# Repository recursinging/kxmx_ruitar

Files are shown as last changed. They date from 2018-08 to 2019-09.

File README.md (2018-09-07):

# kxmx_ruitar

A guitar shaped MIDI/OSC instrument

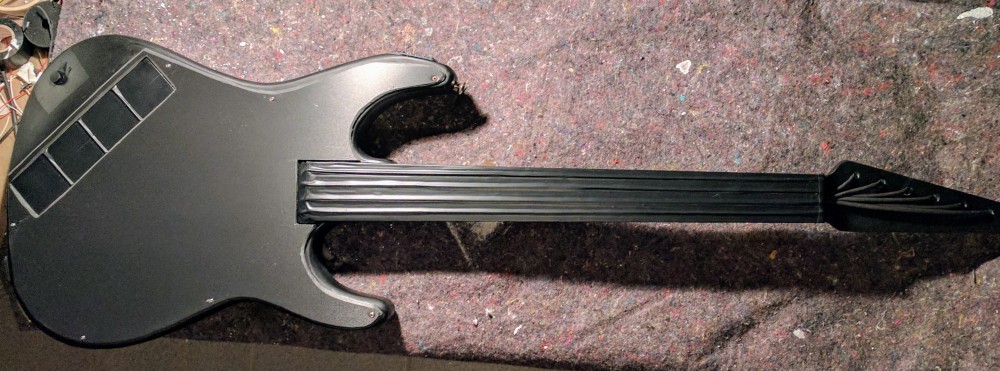
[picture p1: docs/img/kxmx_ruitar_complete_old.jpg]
kxmx_ruitar - Complete - Detail


## The Idea

The goal of this project is pretty simple; Take the general functionality of your typical MIDI keyboard or control surface and implement it (robustly, and with low latency) in the form factor of a guitar.  The motivation is a a little less straightforward. Three things:

1. I wanted to wear it on stage while maintaining the freedom to move about.  
1. I wanted to make it myself.
1. It didn't want to spend a fortune.

I like the form factor of a guitar because it can look quite traditional in a rock band context, but upon closer inspection is clearly not.  This reflects my taste in music, superficially recognizable, but substantially deviant.  While I can play the guitar, I didn't feel it necessary that a functional [guitar be augmented](http://lividinstruments.com/products/guitar-wing/) with MIDI controller capabilities, unless the two can be [seamlessly combined](https://www.rorguitars.com/products/expressiv-midi-pro). This is primarily because my single-threaded brain just cannot effectively handle playing an instrument well, while controlling other parameters. 

Because a guitar hangs down in front of you, facing out, visual controls and feedback are pretty useless.  [A touch screen on the front of the guitar](https://misa-digital.myshopify.com/products/tri-bass) for example, is effectively a touch-pad for the player and a light show for the audience. Therefore I am mostly interested in tactile type sensors which can be blindly interacted with.

The DIY approach is simply an excuse to get lost in the details of interesting technical challenges instead of practicing, or composing actual music. 

Regarding limiting cost... Yeah, anyone who has ever attempted a DIY project like this knows it's actually BS. There is no competing with the economies of scale that a market product has. We DIYers like to trick ourselves by spreading the costs into tiny chunks, over many months. But, I consider the premium an investment in enjoyment and the knowledge gained along the way. So that's how it ended up here.  

## The (current) BOM

* 1 [Teensy 3.6](https://www.pjrc.com/store/teensy36.html) with SD card
* 1 Junk electric guitar, or similarly shaped object.
* 4 500mm [ThinPot](http://www.spectrasymbol.com/product/thinpot/) Membrane Potentiometers (Strings)
* 4 38x38mm [FSR](https://www.interlinkelectronics.com/fsr-406) Pressure Sensors (Pads)
* 1 [Joystick](https://www.adafruit.com/product/444)
* 4 45mm [Slider Potentiometers](https://www.digikey.com/product-detail/en/tt-electronics-bi/PS45-21PC3BR10K/987-1409-ND/2620678) (Faders)
* 4 [LED Buttons](https://www.sparkfun.com/products/10442) (Toggles)
* 1 [SSD1306 64x32 OLED display](https://www.adafruit.com/product/326)
* A diverse set of 0805 SMD resistors and capacitors
* Bits and Bobs (proto board, hookup wire, solder, tape, velcro, etc.)

(With Optional Headstock)

* 1 [Teensy LC](https://www.pjrc.com/teensy/teensyLC.html)
* 4 [RGB LED Rotary Encoders](https://www.sparkfun.com/products/10982)
* 1 [ADXL345 3 Axis Accelerometer](https://www.sparkfun.com/datasheets/Sensors/Accelerometer/ADXL345.pdf) (Accel)
* 1 [TLC5940 PWM Controller](http://www.ti.com/lit/ds/symlink/tlc5940.pdf)
* A diverse set of 0805 SMD resistors and capacitors
* [The ruitar-head PCB]()

## The Build

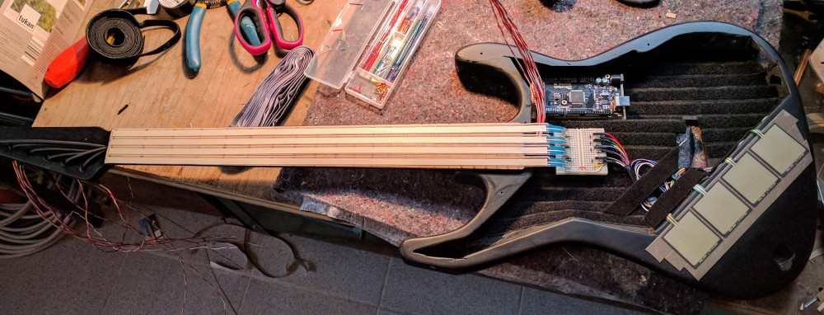
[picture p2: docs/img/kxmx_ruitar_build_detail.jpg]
kxmx_ruitar - Body - Detail


The guitar used was a junk no-name electric.  I hollowed out from the front of the body with an oscillating multi-tool and a wood blade, leaving space for the FSRs.  Because the body is plywood, it was pretty easy to remove the bulk of the material.  I spray-painted everything black and carpeted the inside with adhesive Velcro strips (loop side). This has been quite helpful for cable management and general experimentation.  Just put some hook Velcro to the bottom of a breadboard and stick it in there. Need a USB Hub? Raspberry Pi? Velcro!

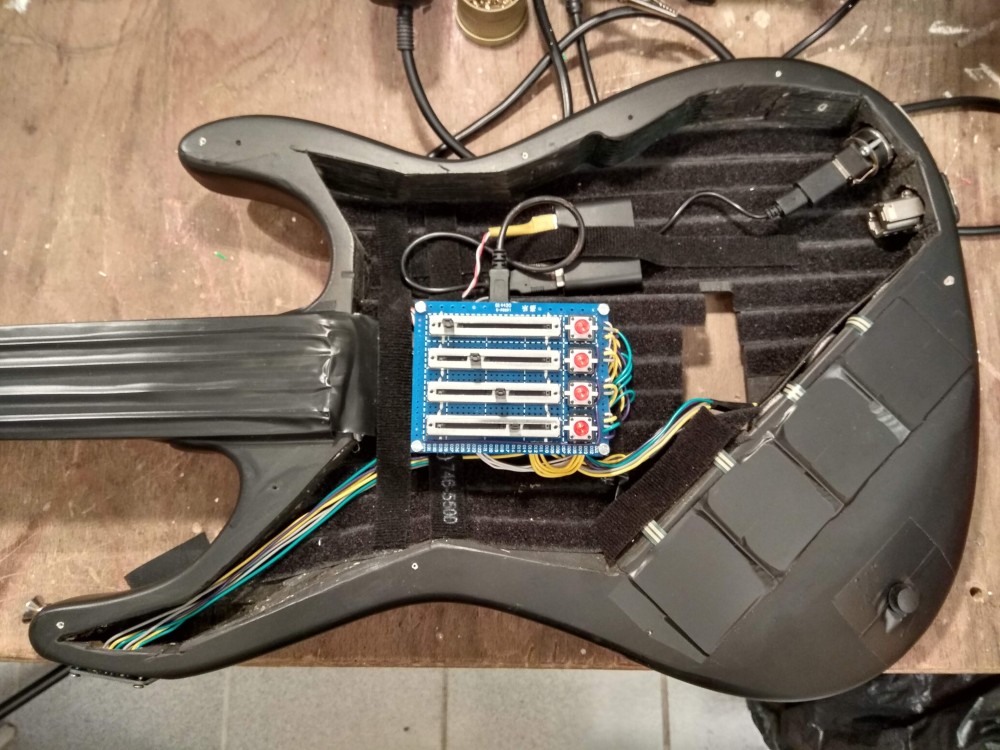
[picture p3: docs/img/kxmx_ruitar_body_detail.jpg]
kxmx_ruitar - Body - Detail


The FSRs are attached with some double sided foam tape which holds them solidly in place and gives them a little bit of padding, which is good when you are banging on them with your knuckles.  The little thumb joystick is mounted in the body with hot glue, and wired through a hole bored into the body cavity. The joystick is meant to be moved with the palm of your hand, allowing you to modulate parameters while tapping on the FSRs... In practice, little thumb joysticks like that are junk, they have too little travel to introduce any decent dynamic.  I am actively looking for an alternative, larger joystick with more travel.

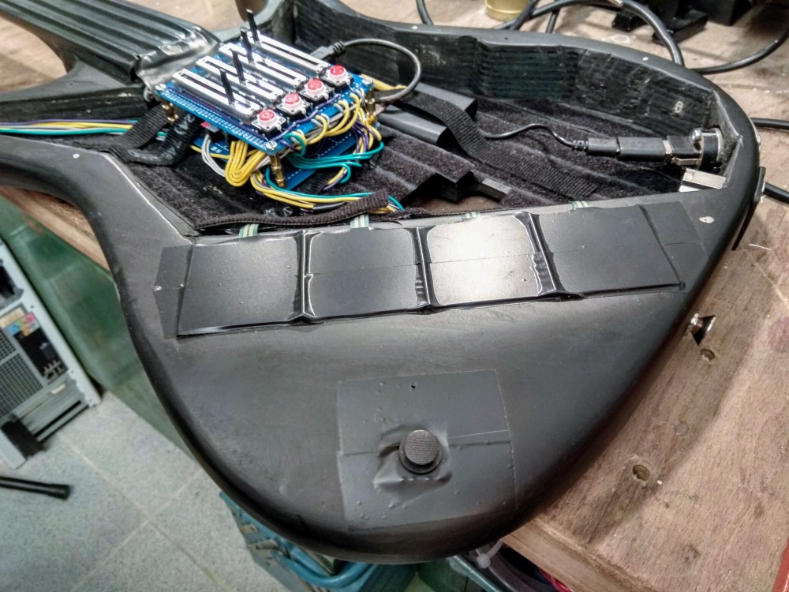
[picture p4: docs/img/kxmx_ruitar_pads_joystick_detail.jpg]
kxmx_ruitar - Body - Detail Pads and Joystick


The first prototype was done using breadboards and an Arduino Mega2650 clone.  When it was finally functional, I found the latency to be unacceptable, the breadboard connections were fragile and problematic,and I also found it lacking interface components.  So, I swapped the Mega2650 for a Teensy 3.6, soldered all the connections using some protoboard, and added the four faders plus four LED buttons. The result is this new prototype module. I'm designing a PCB which will replace this.

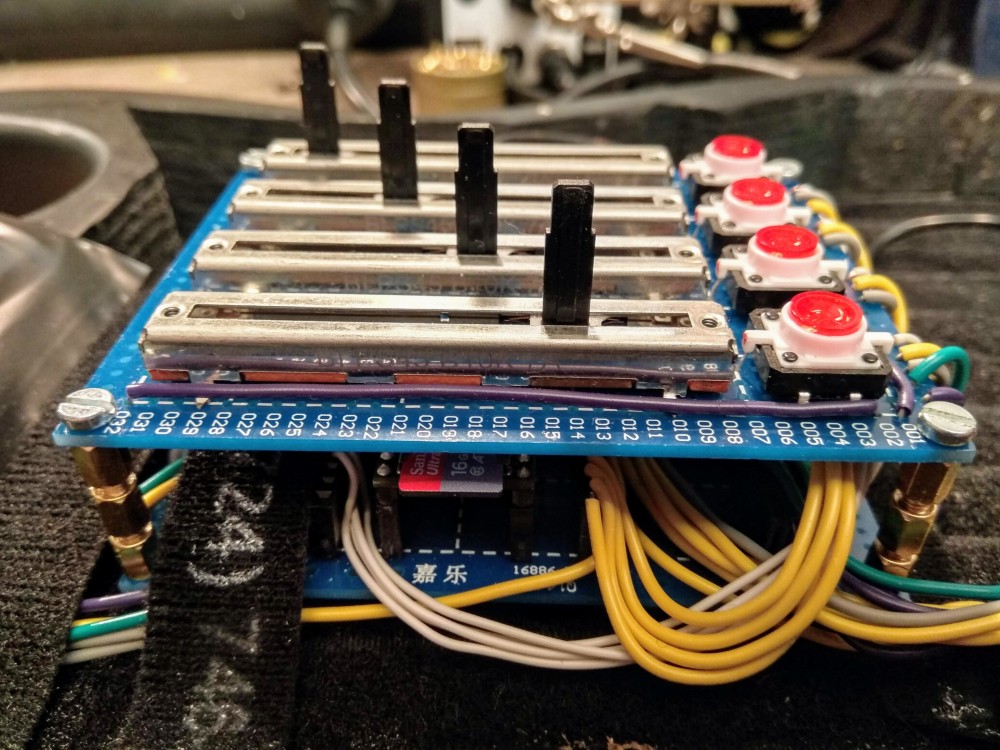
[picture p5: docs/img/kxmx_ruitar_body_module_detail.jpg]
kxmx_ruitar - Body - Detail Faders and Toggles


There are USB-A and RJ-45 jacks to the side using some nice, locking Neutrik jacks.  Because the Teensy's advanced USB capabilities, there is only USB IO at the moment.  The unused RJ-45 is for some future ideas.

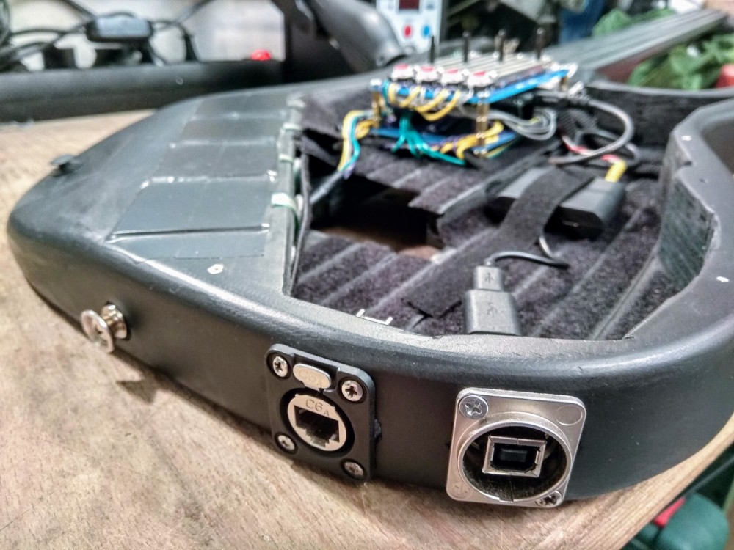
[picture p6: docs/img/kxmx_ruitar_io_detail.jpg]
kxmx_ruitar - IO - Detail


There is an SSD1306 64x32 OLED display mounted to the side of the body of the guitar. I simply flattened a little part of the edge with a belt sander, and drilled a hole into the body cavity for the wires. A 3d-printed protective case surrounding the display would be useful.

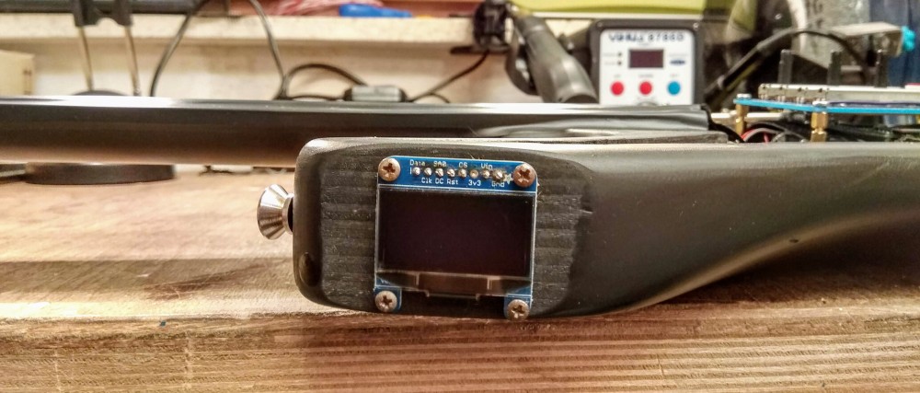
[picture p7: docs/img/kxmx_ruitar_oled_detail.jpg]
kxmx_ruitar - Body - Detail OLED


There is a cover for the body cavity I cut out of plastic to hide the unruly guts (although the aesthetics of the exposed internals are also appealing).  Note that this photo was also taken before the faders and buttons were added, which means that the cover, in that form is not currently usable, but I'm still unsure about the final positions of those components anyhow. 

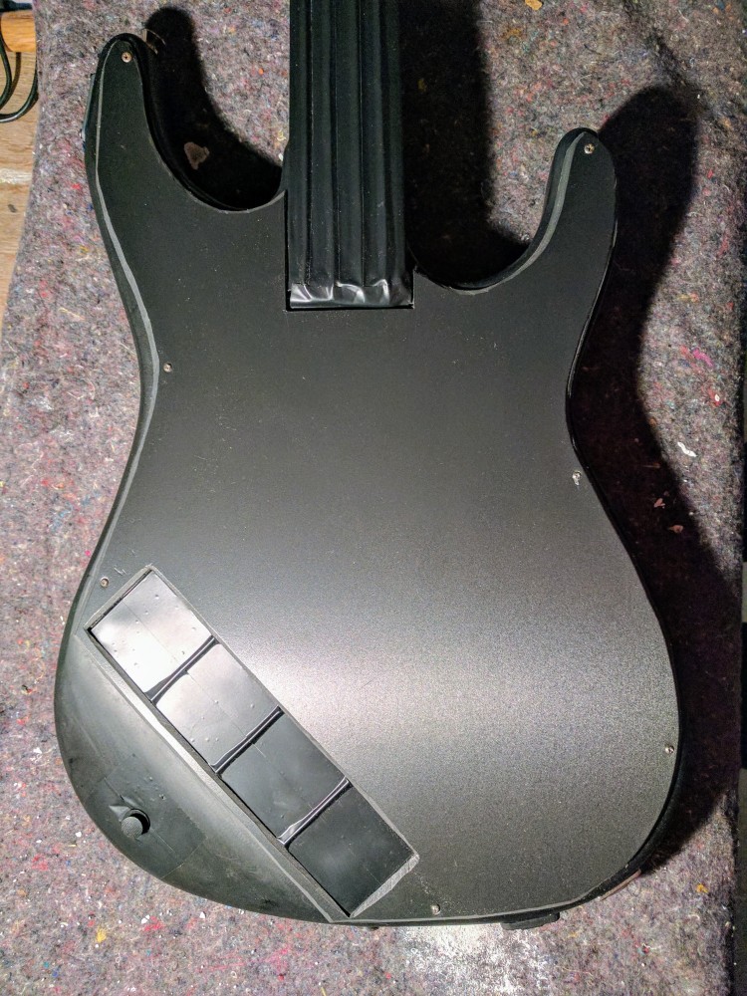
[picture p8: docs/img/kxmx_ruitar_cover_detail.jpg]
kxmx_ruitar - Cover - Detail


The neck was a huge pain. Removing the truss rod required brute force, but afterward I had a cable channel through which I am able to pull wires from the body, up to the head stock. In order to adhere the membrane potentiometers, I needed to flatten the fingerboard. I didn't have any good ideas how, so I ended up just sanding the frets down with a belt sander. There are no photos of this process because I was too busy cursing. The result is OK but if you want to try this yourself, I'd recommend looking for a cheap neck without a fingerboard (although I was unable to find one). Once flattened I attached the membrane potentiometers and covered them with a layer of electrical tape.  I then laid some straightened 14 gauge solid core wire down the middle of each sensor, and put another layer of tape on top.  This provides some tactile feedback as to where the sensors actually are, and really helps the play-ability.  The position tracking through the wire is excellent.

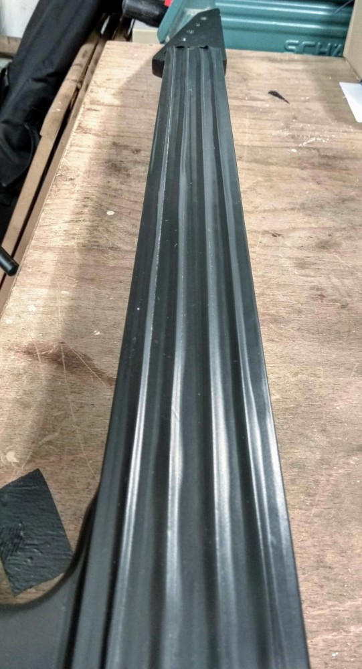
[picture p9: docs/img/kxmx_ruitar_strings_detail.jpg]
kxmx_ruitar - Body - Detail Strings


[The headstock](https://github.com/recursinging/kxmx_ruitar/tree/master/ruitar-head) is a separate entity with its own microcontroller, a ([Teensy LC](https://www.pjrc.com/teensy/teensyLC.html)) acting as an I²C slave device.  It is attached to the headstock of a guitar. I've connected it to the body module with wires pulled through the neck of the guitar.  I removed all the tuning hardware and screwed it directly to the headstock.  Currently, it is quite exposed and fragile.  I'd like to design a 3d printed protective cover for it.

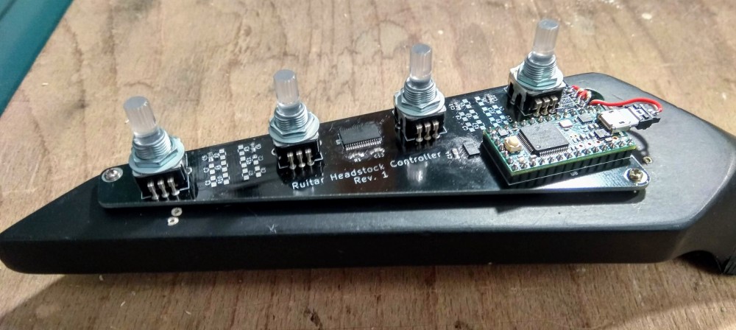
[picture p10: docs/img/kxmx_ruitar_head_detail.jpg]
kxmx_ruitar - Head - Detail


Put all together and you have a ruitar!

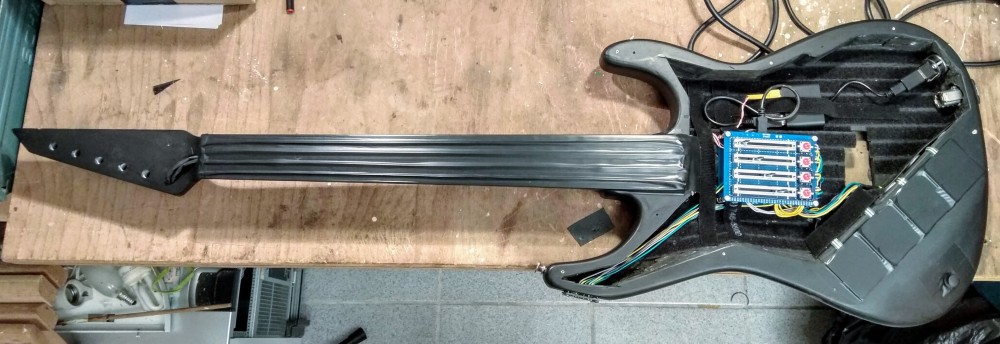
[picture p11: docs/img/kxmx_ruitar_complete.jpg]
kxmx_ruitar - Complete - Current - Detail


## Schematics

TODO

## Firmware

Because the headstock and body have their own microcontrollers, this project is split into two sections, the *ruitar-body* and the *ruitar-head*.  The directory layouts of both projects are currently set up for [platformio](https://platformio.org/), it works. It's not bad.

### [ruitar-body](https://github.com/recursinging/kxmx_ruitar/tree/master/ruitar-head)

The ruitar-body is the core of the instrument, effectively a variety of sensors attached to a microcontroller (a [Teensy 3.6](https://www.pjrc.com/store/teensy36.html)).  These sensors are sampled via the microcontroller ADCs, the values are calculated and, if appropriate, MIDI and OSC messages are sent out. (currently via USB to a PC).

The logic controlling when and what messages to send is configurable by a INI style text files on an SD card. These files can be considered "Presets" and can be copied, modified, renamed, and saved to the SD card.  

TODO - Include config file example

I had plans to make presets configurable through the sensors, and OLED display, but I found the OSC GUI much easier and more powerful, so the OLED display is currently relegated to display some basic debugging info at the moment.  Perhaps there is a better use for it, or the SPI pins it is occupying?

Presets can also be edited via OSC using [the GUI definition](https://github.com/recursinging/kxmx_ruitar/blob/master/osc-gui.json) for [Open Stage Control](https://osc.ammd.net/)

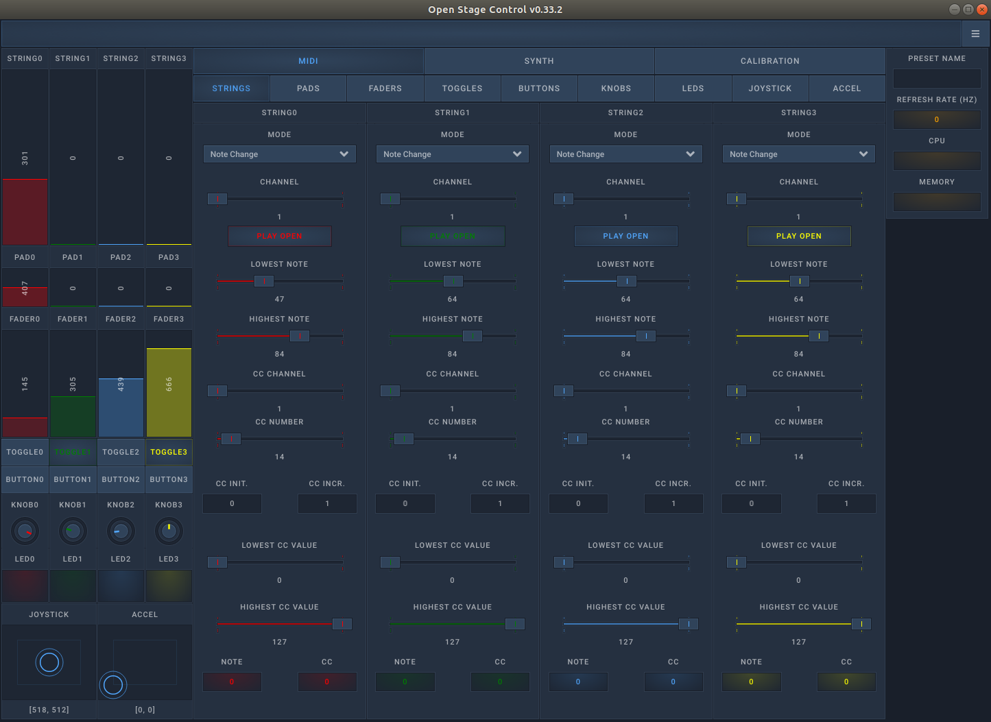
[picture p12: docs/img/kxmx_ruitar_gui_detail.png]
kxmx_ruitar - Body - Detail GUI


The default configuration is for it to behave a bit like a real guitar. Pressing a position on a "string" (0-3) determines the pitch of the note, while triggering the note on state, and its velocity is determined by pressure detected at the associated (0-3) "pad".  The faders, and toggles emit CC messages, and the joystick can emit CC and pitch bend messages. Sensor values received from the head (accelerometer, encoders) can also be configured to emit MIDI CC messages.

### [ruitar-head](https://github.com/recursinging/kxmx_ruitar/tree/master/ruitar-head)

The ruitar-head is set of sensors attached to a microcontroller ([Teensy LC](https://www.pjrc.com/teensy/teensyLC.html)) acting as an I²C slave device. The firmware provides a set of read-only registers which can be read to obtain the accelerometer, and encoder values.  Additionally the state of the RGB LEDs can be polled and changed by a set of read-write registers.

## TODOs

Things that still need to be done, but are incomplete.

- [ ] Design a PCB for the body
- [ ] Fix broken I²C communication between body and head
- [ ] Implement the OSC GUI parameter config
- [ ] Implement the OSC GUI preset copy/rename/save functions
- [ ] Implement a useful MIDI emitter for the accelerometer data
- [ ] Design some 3d printable protective parts for the exposed bits.
- [ ] Provide better descriptions, code comments, build docs, pics, etc

## Future Feature Ideas

A few ideas I've been batting around:

### Synth! 

The Teensy 3.6 is laughing at the current workload.  There is plenty of capacity to implement a digital synth, and the Teensy Audio library is amazing.  I've already started this, but ran into a couple of problems:

* An I²S codec needs quite a few pins, many of which are currently being used
* USB audio is not really an option if you already have a USB audio interface.

Nothing insurmountable, I'd like to make this happen if I find the time.

### Ethernet (or WiFi)

At the moment OSC is provided over SLIP encoded Serial. This works, but is a kludge requiring [a bridge program](https://github.com/recursinging/kxmx_trestle) to get the UDP packets that all the OSC clients expect.

There is a Neutrik RJ-45 jack built into the body of the ruitar,  I could provide power over the unused pairs assuming 100-BASE-T.  But without the USB cable I would loose all the USB* devices the Teensy can emulate, which would be a bummer. 

Alternatively I could send the SLIP serial to an ESP32 and broadcast the OSC packets via WiFi, not sure about the latency though. 

### Membrane Potentiometer Alternatives

The kxmx_ruitar is *really* hard to play.  Tracking on the "strings" is not bad, but the lack of any tactile feedback along them makes it difficult to get a position reference. Anyway, since MIDI notes are discrete, all the position data the pot and ADC could provide gets quantized to the configured 20 note range anyway... They might as well be buttons, right?

## Inspiration, Ideas, and Prior Art

Here's a list of products and projects from which I have gathered ideas:

* [Misa Digital Tri-Bass](https://misa-digital.myshopify.com/products/tri-bass)
* [Starr Labs Z-Tars](https://www.starrlabs.com/product/z6s/)
* [Expressiv MIDI Pro](https://www.rorguitars.com/products/expressiv-midi-pro)
* [Alesis Vortex](https://www.alesis.com/products/view2/vortex-wireless-2)

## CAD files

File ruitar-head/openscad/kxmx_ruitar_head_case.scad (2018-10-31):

module headstock (){
  difference() {
    translate ([(192-29)-13,0,0]){
     difference () {
         translate ([0,-20,0]) difference () {
             translate ([-192+29,-30.5,-1]) cube([192,61,1]);
             translate ([29,0,-2]) rotate([0,0,43.5]) cube([50,50,3]);
             translate ([29,0,-2]) rotate([0,0,-133.6]) cube([50,50,3]);
         }
        translate ([-192,-55,-2]) rotate ([0,0,-17]) cube([192,61,3]);
     }
    }
  translate ([-13,0,-2]) rotate ([0,0,39]) cube([20,20,3]);
  }
}

module case (){
  difference() {
    translate ([(192-29)-13,0,0]){
     difference () {
         translate ([0,-20,0]) difference () {
             translate ([-192+29,-30.5,0]) cube([192,61,9.5]);
             translate ([29,0,-1]) rotate([0,0,43.5]) cube([50,50,11]);
             translate ([29,0,-1]) rotate([0,0,-133.6]) cube([50,50,11]);
         }
        translate ([-192,-55,-1]) rotate ([0,0,-17]) cube([192,61,11]);
     }
    }
  translate ([-13,0,-1]) rotate ([0,0,39]) cube([20,20,11]);
  translate ([0,-50,+4]) rotate ([10,0,0]) cube([200,50,11]);
  }
}
color("Pink") case();
headstock();

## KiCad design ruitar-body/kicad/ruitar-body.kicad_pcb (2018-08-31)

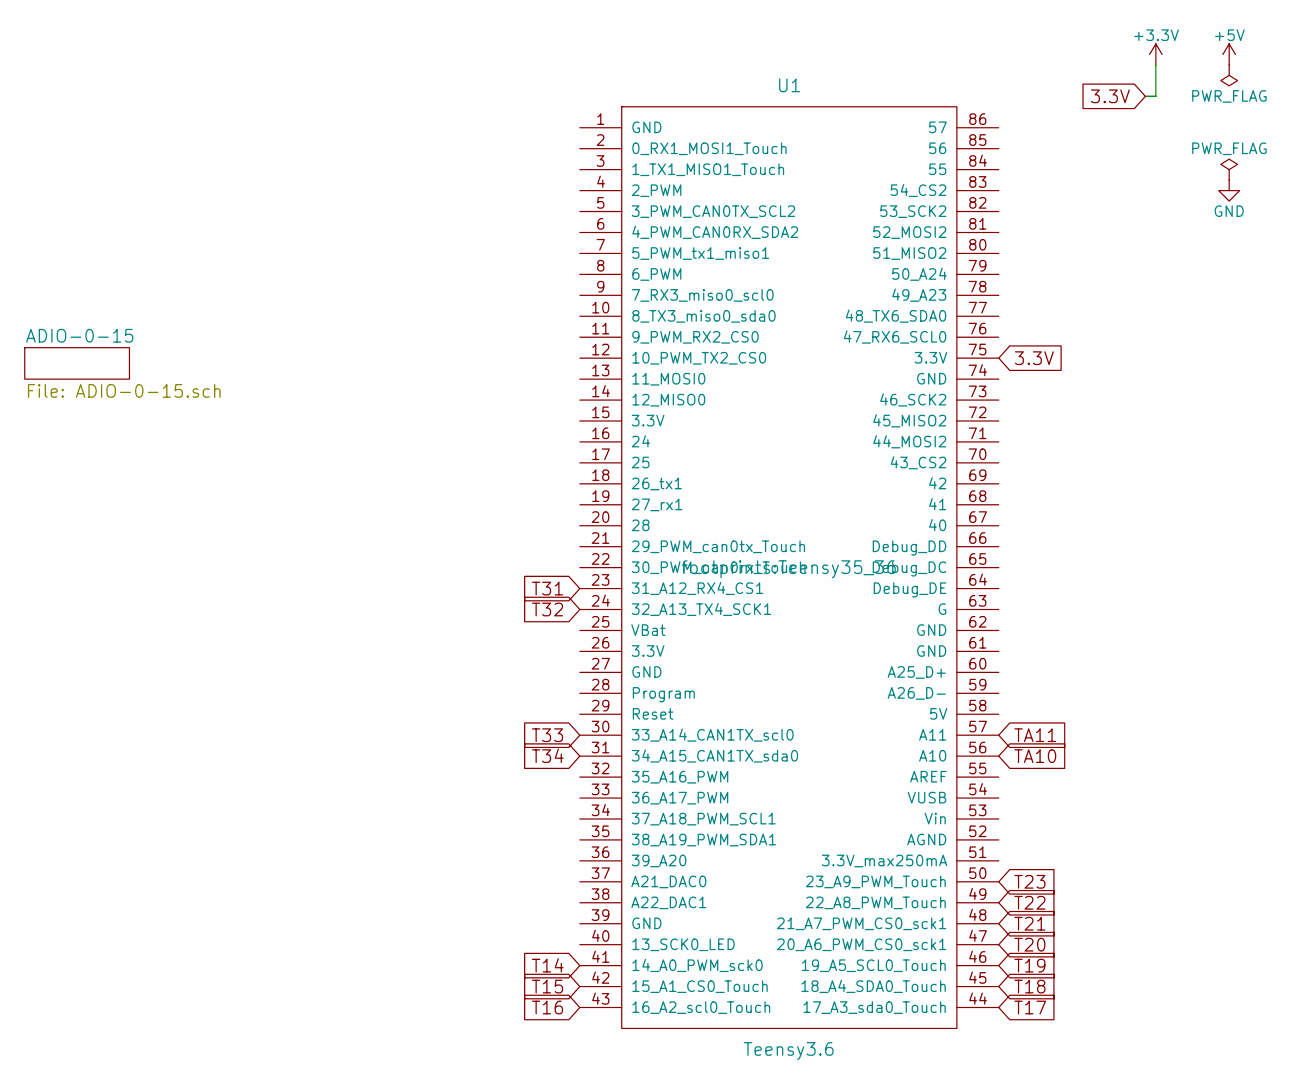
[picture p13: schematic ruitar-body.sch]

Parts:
U1: Teensy3.6; Teensy35_36

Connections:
3.3V: U1.75 (3.3V); also elsewhere on the board
T14: U1.41 (14_A0_PWM_sck0); also elsewhere on the board
T15: U1.42 (15_A1_CS0_Touch); also elsewhere on the board
T16: U1.43 (16_A2_scl0_Touch); also elsewhere on the board
T17: U1.44 (17_A3_sda0_Touch); also elsewhere on the board
T18: U1.45 (18_A4_SDA0_Touch); also elsewhere on the board
T19: U1.46 (19_A5_SCL0_Touch); also elsewhere on the board
T20: U1.47 (20_A6_PWM_CS0_sck1); also elsewhere on the board
T21: U1.48 (21_A7_PWM_CS0_sck1); also elsewhere on the board
T22: U1.49 (22_A8_PWM_Touch); also elsewhere on the board
T23: U1.50 (23_A9_PWM_Touch); also elsewhere on the board
T31: U1.23 (31_A12_RX4_CS1); also elsewhere on the board
T32: U1.24 (32_A13_TX4_SCK1); also elsewhere on the board
T33: U1.30 (33_A14_CAN1TX_scl0); also elsewhere on the board
T34: U1.31 (34_A15_CAN1TX_sda0); also elsewhere on the board
TA10: U1.56 (A10); also elsewhere on the board
TA11: U1.57 (A11); also elsewhere on the board

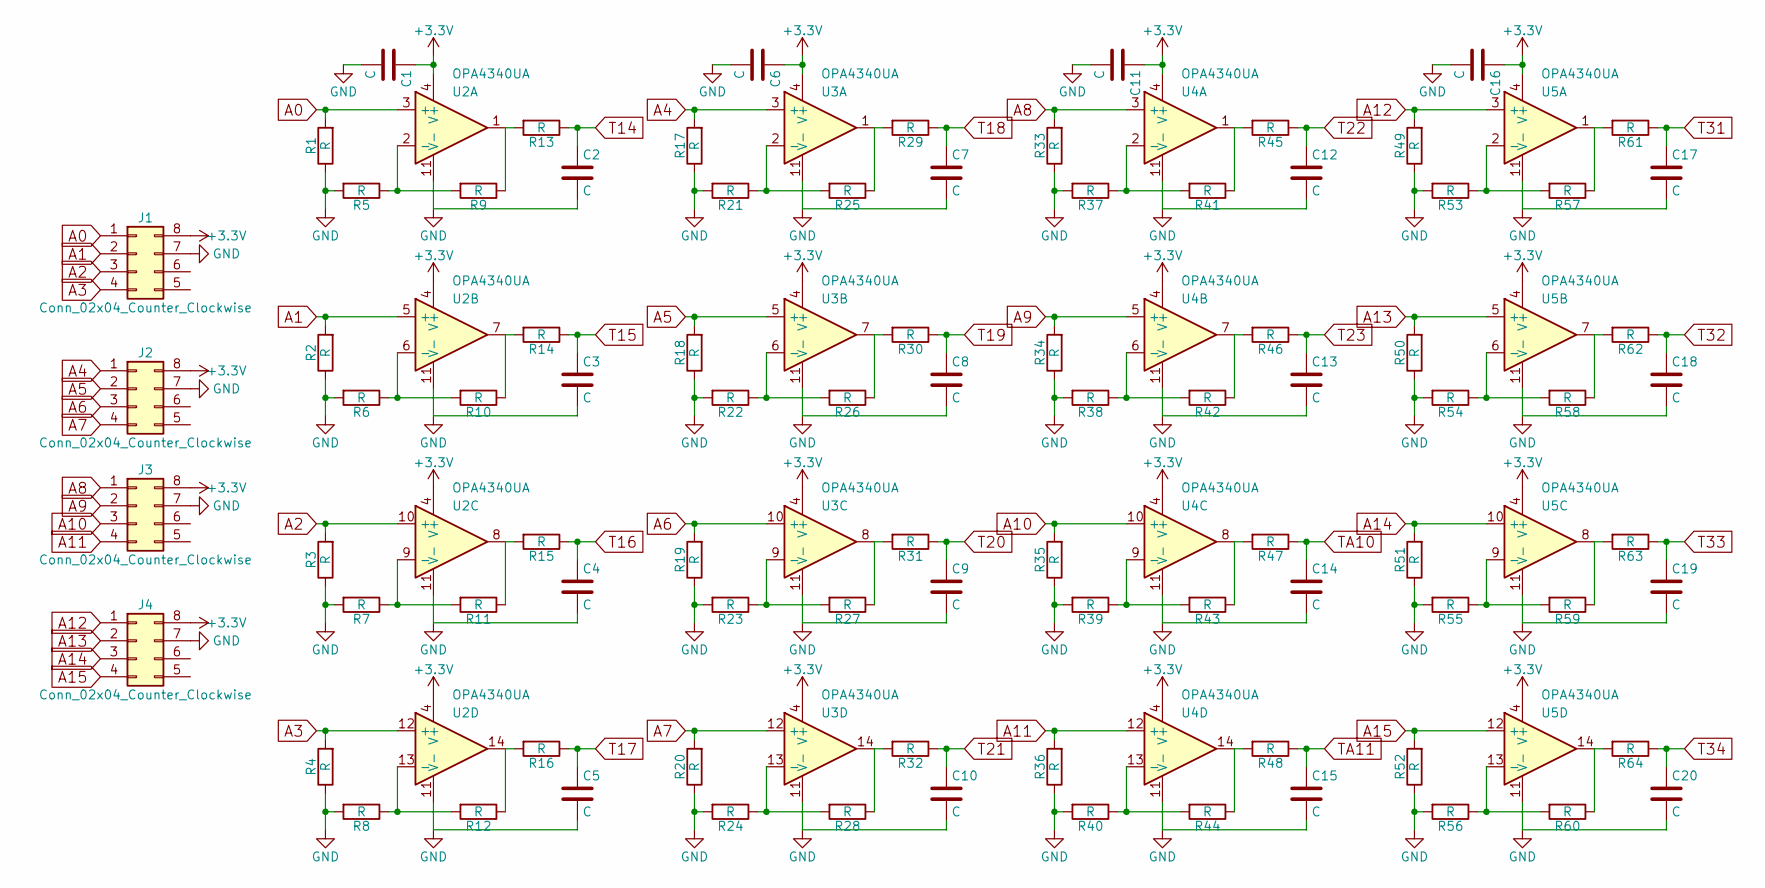
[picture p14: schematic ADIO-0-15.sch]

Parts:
C1, C2, C3, C4, C5, C6, C7, C8, C9, C10, C11, C12, C13, C14, C15, C16, C17, C18, C19, C20: C; C_0805
J1, J2, J3, J4: Conn_02x04_Counter_Clockwise; RJ45_8
R1, R2, R3, R4, R5, R6, R7, R8, R9, R10, R11, R12, R13, R14, R15, R16, R17, R18, R19, R20, R21, R22, R23, R24, R25, R26, R27, R28, R29, R30, R31, R32, R33, R34, R35, R36, R37, R38, R39, R40, R41, R42, R43, R44, R45, R46, R47, R48, R49, R50, R51, R52, R53, R54, R55, R56, R57, R58, R59, R60, R61, R62, R63, R64: R; R_0805
U2, U3, U4, U5: OPA4340UA; SOIC-14_3.9x8.7mm_Pitch1.27mm

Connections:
3.3V: C1.1, C6.1, C11.1, C16.1, J1.8, J2.8, J3.8, J4.8, U2.4 (V+), U3.4 (V+), U4.4 (V+), U5.4 (V+); also elsewhere on the board
A0: J1.1, R1.2, U2.3 (+)
A1: J1.2, R2.2, U2.5 (+)
A2: J1.3, R3.2, U2.10 (+)
A3: J1.4, R4.2, U2.12 (+)
A4: J2.1, R17.2, U3.3 (+)
A5: J2.2, R18.2, U3.5 (+)
A6: J2.3, R19.2, U3.10 (+)
A7: J2.4, R20.2, U3.12 (+)
A8: J3.1, R33.2, U4.3 (+)
A9: J3.2, R34.2, U4.5 (+)
A10: J3.3, R35.2, U4.10 (+)
A11: J3.4, R36.2, U4.12 (+)
A12: J4.1, R49.2, U5.3 (+)
A13: J4.2, R50.2, U5.5 (+)
A14: J4.3, R51.2, U5.10 (+)
A15: J4.4, R52.2, U5.12 (+)
GND: C1.2, C2.2, C3.2, C4.2, C5.2, C6.2, C7.2, C8.2, C9.2, C10.2, C11.2, C12.2, C13.2, C14.2, C15.2, C16.2, C17.2, C18.2, C19.2, C20.2, J1.7, J2.7, J3.7, J4.7, R1.1, R2.1, R3.1, R4.1, R5.2, R6.2, R7.2, R8.2, R17.1, R18.1, R19.1, R20.1, R21.2, R22.2, R23.2, R24.2, R33.1, R34.1, R35.1, R36.1, R37.2, R38.2, R39.2, R40.2, R49.1, R50.1, R51.1, R52.1, R53.2, R54.2, R55.2, R56.2, U2.11 (V-), U3.11 (V-), U4.11 (V-), U5.11 (V-)
unnamed: R5.1, R9.2, U2.2 (-)
unnamed: R10.1, R14.2, U2.7
unnamed: R6.1, R10.2, U2.6 (-)
unnamed: R11.1, R15.2, U2.8
unnamed: R7.1, R11.2, U2.9 (-)
unnamed: R12.1, R16.2, U2.14
unnamed: R8.1, R12.2, U2.13 (-)
unnamed: R9.1, R13.2, U2.1
unnamed: R21.1, R25.2, U3.2 (-)
unnamed: R22.1, R26.2, U3.6 (-)
unnamed: R23.1, R27.2, U3.9 (-)
unnamed: R24.1, R28.2, U3.13 (-)
unnamed: R25.1, R29.2, U3.1
unnamed: R26.1, R30.2, U3.7
unnamed: R27.1, R31.2, U3.8
unnamed: R28.1, R32.2, U3.14
unnamed: R37.1, R41.2, U4.2 (-)
unnamed: R38.1, R42.2, U4.6 (-)
unnamed: R39.1, R43.2, U4.9 (-)
unnamed: R40.1, R44.2, U4.13 (-)
unnamed: R41.1, R45.2, U4.1
unnamed: R42.1, R46.2, U4.7
unnamed: R43.1, R47.2, U4.8
unnamed: R44.1, R48.2, U4.14
unnamed: R53.1, R57.2, U5.2 (-)
unnamed: R54.1, R58.2, U5.6 (-)
unnamed: R55.1, R59.2, U5.9 (-)
unnamed: R56.1, R60.2, U5.13 (-)
unnamed: R57.1, R61.2, U5.1
unnamed: R58.1, R62.2, U5.7
unnamed: R59.1, R63.2, U5.8
unnamed: R60.1, R64.2, U5.14
T14: C2.1, R13.1; also elsewhere on the board
T15: C3.1, R14.1; also elsewhere on the board
T16: C4.1, R15.1; also elsewhere on the board
T17: C5.1, R16.1; also elsewhere on the board
T18: C7.1, R29.1; also elsewhere on the board
T19: C8.1, R30.1; also elsewhere on the board
T20: C9.1, R31.1; also elsewhere on the board
T21: C10.1, R32.1; also elsewhere on the board
T22: C12.1, R45.1; also elsewhere on the board
T23: C13.1, R46.1; also elsewhere on the board
T31: C17.1, R61.1; also elsewhere on the board
T32: C18.1, R62.1; also elsewhere on the board
T33: C19.1, R63.1; also elsewhere on the board
T34: C20.1, R64.1; also elsewhere on the board
TA10: C14.1, R47.1; also elsewhere on the board
TA11: C15.1, R48.1; also elsewhere on the board

Board: 2 copper layers, 93 parts (0 on the bottom side), 66 nets, no tracks yet.

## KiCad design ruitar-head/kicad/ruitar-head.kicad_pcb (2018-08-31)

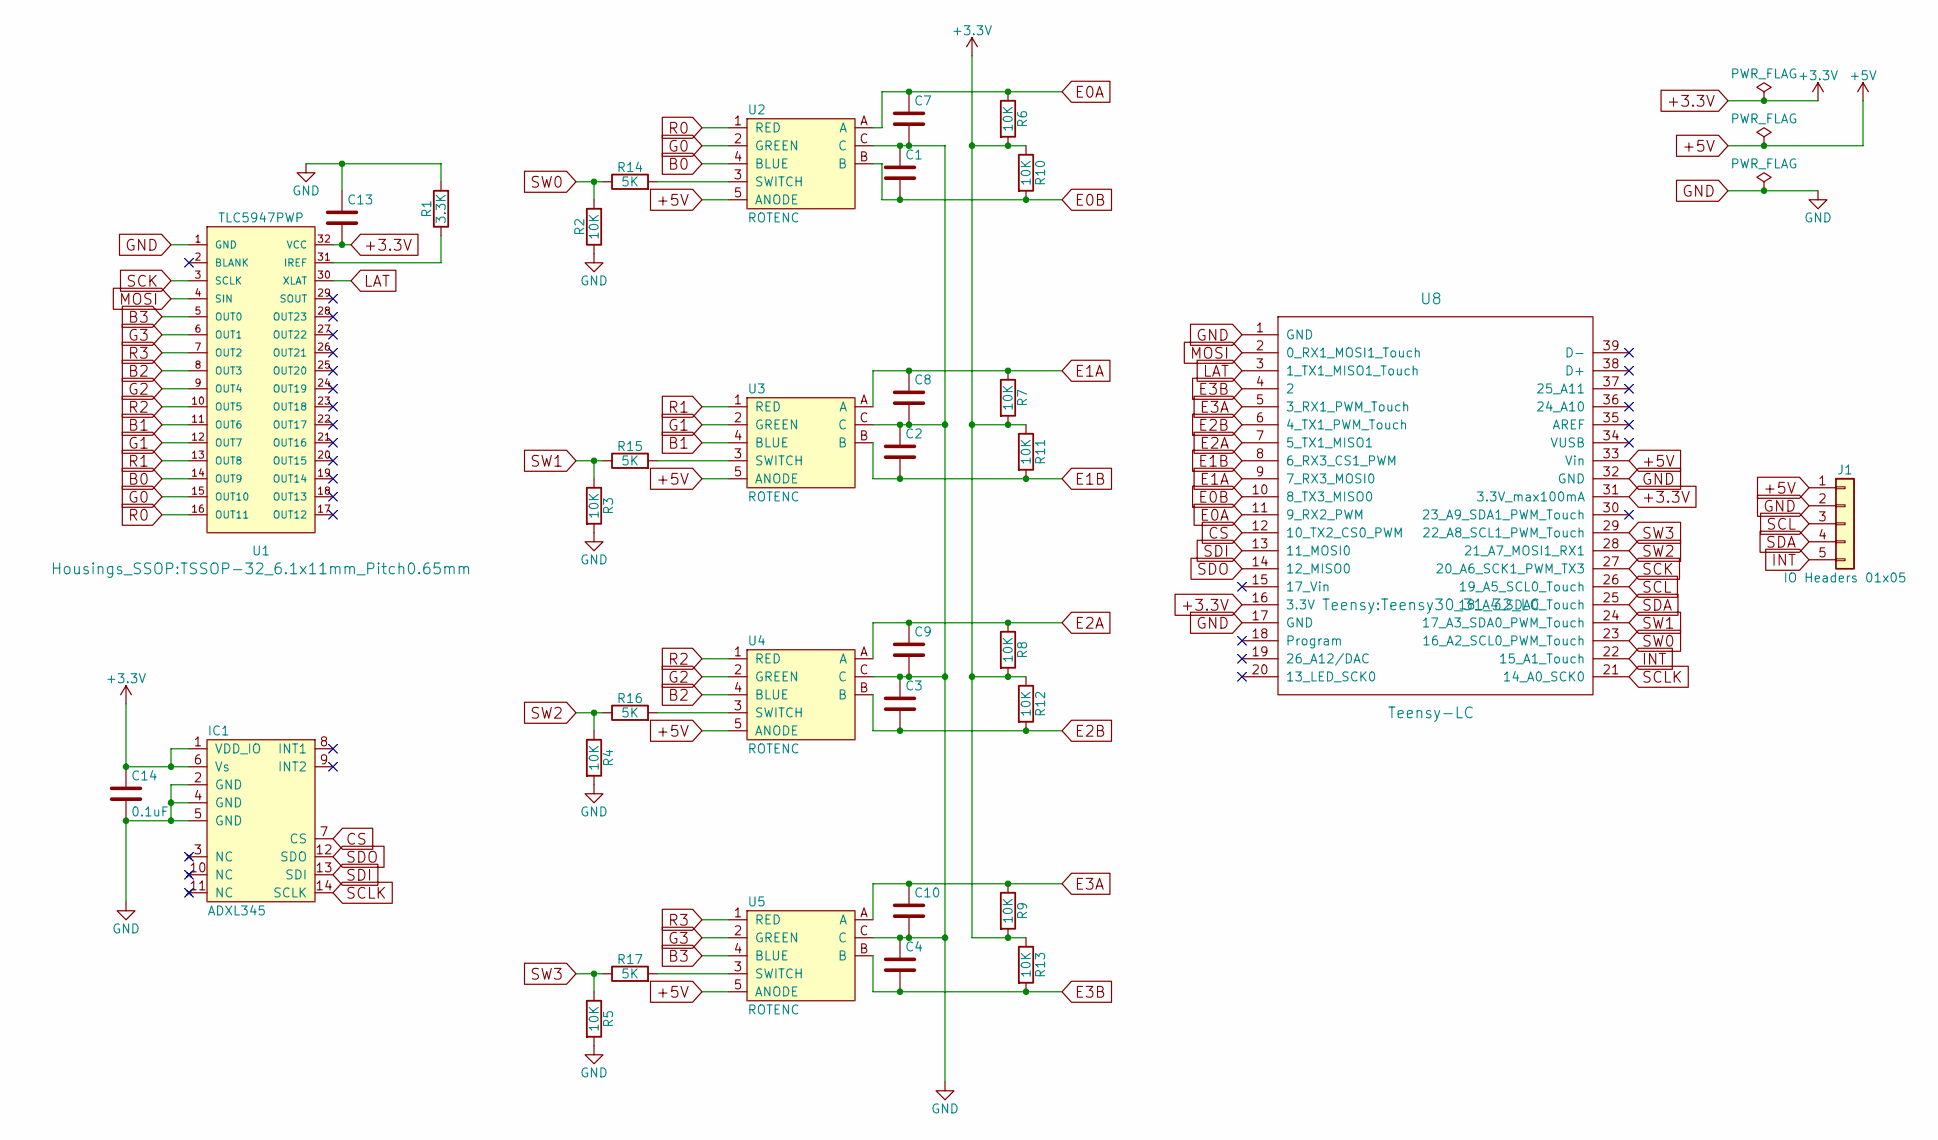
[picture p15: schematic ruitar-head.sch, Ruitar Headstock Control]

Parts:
C1, C2, C3, C4, C7, C8, C9, C10, C13, C14: 0.1uF; C_0805_HandSoldering
IC1: ADXL345; ADXL3x5; Farnell 1853935
J1: IO Headers 01x05; Pin_Header_Straight_1x05_Pitch2.54mm
R1: 3.3K; R_0805_HandSoldering
R2, R3, R4, R5, R6, R7, R8, R9, R10, R11, R12, R13: 10K; R_0805_HandSoldering
R14, R15, R16, R17: 5K; R_0805_HandSoldering
U1: TLC5947PWP; TSSOP-32_6.1x11mm_Pitch0.65mm
U2, U3, U4, U5: ROTENC; SF_ROTENC
U8: Teensy-LC; Teensy30_31_32_LC

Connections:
+3.3V: C13.2, C14.1, IC1.1 (VDD_IO), IC1.6 (Vs), R6.2, R7.2, R8.2, R9.2, R10.1, R11.1, R12.1, R13.1, U1.32 (VCC), U8.16 (3.3V), U8.31 (3.3V_max100mA)
+5V: J1.1, U2.5 (ANODE), U3.5 (ANODE), U4.5 (ANODE), U5.5 (ANODE), U8.33 (Vin)
B0: U1.14 (OUT9), U2.4 (BLUE)
B1: U1.11 (OUT6), U3.4 (BLUE)
B2: U1.8 (OUT3), U4.4 (BLUE)
B3: U1.5 (OUT0), U5.4 (BLUE)
CS: IC1.7 (CS), U8.12 (10_TX2_CS0_PWM)
E0A: C7.1, R6.1, U2.A, U8.11 (9_RX2_PWM)
E0B: C1.2, R10.2, U2.B, U8.10 (8_TX3_MISO0)
E1A: C8.1, R7.1, U3.A, U8.9 (7_RX3_MOSI0)
E1B: C2.2, R11.2, U3.B, U8.8 (6_RX3_CS1_PWM)
E2A: C9.1, R8.1, U4.A, U8.7 (5_TX1_MISO1)
E2B: C3.2, R12.2, U4.B, U8.6 (4_TX1_PWM_Touch)
E3A: C10.1, R9.1, U5.A, U8.5 (3_RX1_PWM_Touch)
E3B: C4.2, R13.2, U5.B, U8.4 (2)
G0: U1.15 (OUT10), U2.2 (GREEN)
G1: U1.12 (OUT7), U3.2 (GREEN)
G2: U1.9 (OUT4), U4.2 (GREEN)
G3: U1.6 (OUT1), U5.2 (GREEN)
GND: C1.1, C2.1, C3.1, C4.1, C7.2, C8.2, C9.2, C10.2, C13.1, C14.2, IC1.2 (GND), IC1.4 (GND), IC1.5 (GND), J1.2, R1.2, R2.1, R3.2, R4.2, R5.2, U1.1 (GND), U2.C, U3.C, U4.C, U5.C, U8.1 (GND), U8.17 (GND), U8.32 (GND)
INT: J1.5, U8.22 (15_A1_Touch)
LAT: U1.30 (XLAT), U8.3 (1_TX1_MISO1_Touch)
MOSI: U1.4 (SIN), U8.2 (0_RX1_MOSI1_Touch)
unnamed: R1.1, U1.31 (IREF)
unnamed: R14.2, U2.3 (SWITCH)
unnamed: R15.2, U3.3 (SWITCH)
unnamed: R16.2, U4.3 (SWITCH)
unnamed: R17.2, U5.3 (SWITCH)
R0: U1.16 (OUT11), U2.1 (RED)
R1: U1.13 (OUT8), U3.1 (RED)
R2: U1.10 (OUT5), U4.1 (RED)
R3: U1.7 (OUT2), U5.1 (RED)
SCK: U1.3 (SCLK), U8.27 (20_A6_SCK1_PWM_TX3)
SCL: J1.3, U8.26 (19_A5_SCL0_Touch)
SCLK: IC1.14 (SCLK), U8.21 (14_A0_SCK0)
SDA: J1.4, U8.25 (18_A4_SDA0_Touch)
SDI: IC1.13 (SDI), U8.13 (11_MOSI0)
SDO: IC1.12 (SDO), U8.14 (12_MISO0)
SW0: R2.2, R14.1, U8.23 (16_A2_SCL0_PWM_Touch)
SW1: R3.1, R15.1, U8.24 (17_A3_SDA0_PWM_Touch)
SW2: R4.1, R16.1, U8.28 (21_A7_MOSI1_RX1)
SW3: R5.1, R17.1, U8.29 (22_A8_SCL1_PWM_Touch)

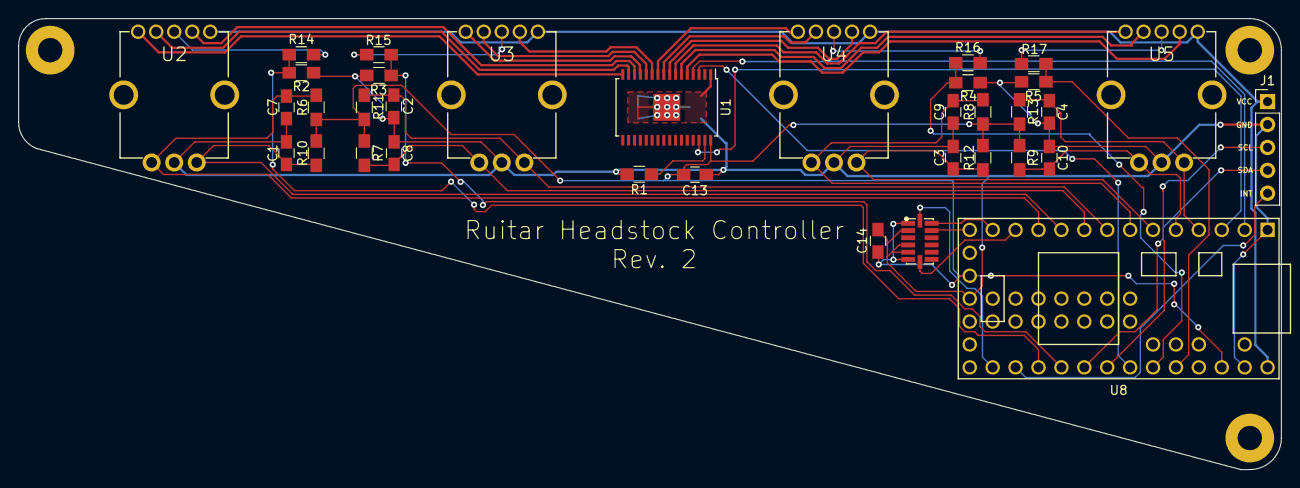
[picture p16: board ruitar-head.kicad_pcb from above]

Board: 2 copper layers, 140.0 x 50.0 mm, 35 parts (0 on the bottom side), 42 nets.

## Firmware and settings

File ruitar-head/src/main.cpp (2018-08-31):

#include "Encoder.h"
#include "Accelerometer.h"
#include "i2c_t3.h"
#include "Adafruit_TLC5947.h"
#include "RuitarHeadDefines.h"

#define KNOB_0A 9
#define KNOB_0B 8
#define KNOB_1A 7
#define KNOB_1B 6
#define KNOB_2A 5
#define KNOB_2B 4
#define KNOB_3A 3
#define KNOB_3B 2

#define SW0 16
#define SW1 17
#define SW2 21
#define SW3 22

#define LEDPWM_DAT 0
#define LEDPWM_LAT 1
#define LEDPWM_CLK 20

#define HEAD_RESET 15


// Function prototypes
void receiveEvent(size_t count);
void requestEvent(void);
void isrSW0();
void isrSW1();
void isrSW2();
void isrSW3();
void pr_byte(uint8_t val);
void allRegisters(void);

Encoder knob0 = Encoder(KNOB_0B, KNOB_0A);
Encoder knob1 = Encoder(KNOB_1B, KNOB_1A);
Encoder knob2 = Encoder(KNOB_2B, KNOB_2A);
Encoder knob3 = Encoder(KNOB_3B, KNOB_3A);

Accelerometer adxl = Accelerometer();

//LEDPWM pwm = LEDPWM(LEDPWM_DAT, LEDPWM_LAT, LEDPWM_CLK);
Adafruit_TLC5947 pwm = Adafruit_TLC5947(1, LEDPWM_CLK, LEDPWM_DAT, LEDPWM_LAT);

uint8_t _reg[RH_REG_LEN];
volatile uint8_t _read;
volatile uint8_t _mod;
volatile uint8_t _cmd;
volatile uint8_t _state;
volatile size_t _addr;

uint32_t _elapsed;
uint16_t _rate;
uint8_t _debug;

void initialize() {
  // Setup for Slave mode, address 0x44, pins 18/19, external pullups, 400kHz
  Wire.begin(I2C_SLAVE, RH_ADDR, I2C_PINS_18_19, I2C_PULLUP_EXT, RH_FREQ);
  Wire.resetBus();
  // register events
  Wire.onReceive(receiveEvent);
  Wire.onRequest(requestEvent);
}

void setup() {
  Serial.begin(115200);
  delay(500);
  Serial.println("Setting up the Ruitar Head...");

  // init vars
  _reg[RH_REG_LEN] = {0};
  _debug = 1;
  _read = 0;
  _mod = 0;
  _cmd = 0;
  _addr = 0;
  _state = 0;
  _elapsed = 0;
  _rate = 0;

  pinMode(SW0, INPUT);
  attachInterrupt(SW0, isrSW0, CHANGE);

  pinMode(SW1, INPUT);
  attachInterrupt(SW1, isrSW1, CHANGE);

  pinMode(SW2, INPUT);
  attachInterrupt(SW2, isrSW2, CHANGE);

  pinMode(SW3, INPUT);
  attachInterrupt(SW3, isrSW3, CHANGE);

  pinMode(HEAD_RESET, INPUT_PULLUP);

  initialize();

  delay(100);

  Serial.print("Starting the ADXL...");
  adxl.begin();
  Serial.println("...OK");

  delay(100);
  Serial.print("Starting the PWM controller...");
  pwm.begin();
  Serial.println("...OK");

  delay(100);
  pinMode(LED_BUILTIN, OUTPUT);
   Serial.print("Blinking...");
  for (size_t i = 0; i < 4; i++) {
    digitalWrite(LED_BUILTIN, HIGH);
    delay(50);
    digitalWrite(LED_BUILTIN, LOW);
    delay(50);
    digitalWrite(LED_BUILTIN, HIGH);
  }

  delay(100);

  uint16_t on = 4096;
  uint16_t off = 0;
  for (int i = 0; i < 12; i++) {
    pwm.setPWM(i, on);
    pwm.write();
    delay(50);
    pwm.setPWM(i, off);
    pwm.write();
    delay(50);
  }
  Serial.println("...OK");

  Serial.println("...finished");
}

uint32_t indicateReset = 0;

void loop() {

//  Serial.println("OK");
//  delay(1000);

  uint32_t start = micros();

  // Always read the ADXL and poll the knobs and buttons
  adxl.read(&_reg[RH_ACCLX]);

  _reg[RH_K0CNT] = (int8_t) knob0.read() / 4;
  _reg[RH_K1CNT] = (int8_t) knob1.read() / 4;
  _reg[RH_K2CNT] = (int8_t) knob2.read() / 4;
  _reg[RH_K3CNT] = (int8_t) knob3.read() / 4;
  _reg[RH_STATE] = _state;

  if (_read) {
    // Values have been read... reset now.
    knob0.write(0);
    knob1.write(0);
    knob2.write(0);
    knob3.write(0);
    memset(&_reg[RH_K0CNT], 0, 4);
    _read = 0;
  }

  if (_mod) {
    // Write PWM Registers
   // Serial.println("Write PWM Registers:");
    for (int i = 12; i > 0; i--) {
      int ledIdx = i - 1;
      int msbIdx = (i * 2) - 1;
      int lsbIdx = (i * 2) - 2;
      uint16_t intensity = (uint16_t) ((((uint16_t) _reg[msbIdx]) << 8) | _reg[lsbIdx]);
      pwm.setPWM(ledIdx, intensity);
    }
    pwm.write();
    _mod = 0;
  }

  uint32_t elapsed = (micros() - start);
  _elapsed += elapsed;
  _rate++;
  if (_elapsed > 500000) {
    _reg[RH_RFRSH] = _rate >> 8;
    _reg[RH_RFRSH + 1] = (uint8_t) _rate;
    _elapsed = 0;
    _rate = 0;
    if (_debug) {
      allRegisters();
    }
  }

}

//
// handle Rx Event (incoming I2C request/data)
//
void receiveEvent(size_t count) {
  if (count) {
    // grab command
    _cmd = Wire.readByte();

    Serial.print("Got CMD: ");
    Serial.println(_cmd);

    count--;
    switch (_cmd) {
    case RH_WRITE:
      _addr = Wire.readByte();         // grab _addr
      count--;
      if (count && (_addr + count) < RH_STATE) { // STATE is the RW Boundary register
        Wire.read(&_reg[_addr], count); // copy Rx data to register buffer
        _mod = 1;
      }
      break;

    case RH_READ:
      _addr = Wire.readByte();                // grab _addr
      break;
    }
  }
}

//
// handle Tx Event (outgoing I2C data)
//
void requestEvent(void) {
  switch (_cmd) {
  case RH_READ:
    //Serial.println("HEAD Recieved READ command");
    Wire.write(&_reg[_addr], RH_REG_LEN - _addr); // fill Tx buffer (from _addr location to end of mem)
    break;
  }
}

void isrSW0() {
  _state = (_state & ~(1 << RH_SW0BIT)) | (digitalReadFast(SW0) << RH_SW0BIT);
}

void isrSW1() {
  _state = (_state & ~(1 << RH_SW1BIT)) | (digitalReadFast(SW1) << RH_SW1BIT);
}

void isrSW2() {
  _state = (_state & ~(1 << RH_SW2BIT)) | (digitalReadFast(SW2) << RH_SW2BIT);
}

void isrSW3() {
  _state = (_state & ~(1 << RH_SW3BIT)) | (digitalReadFast(SW3) << RH_SW3BIT);
}

void pr_byte(uint8_t val) {
  int i;
  Serial.print("B");
  for (i = 7; i >= 0; i--) {
    Serial.print(val >> i & 1, BIN);
  }
}

void allRegisters(void) {
  Serial.println("#### Registers ####");
  Serial.print("K0LEDR - RW - ");
  Serial.print(RH_K0LEDR, HEX);
  Serial.print(" - ");
  Serial.println(
      (uint16_t) ((((uint16_t) _reg[RH_K0LEDR + 1]) << 8) | _reg[RH_K0LEDR]));
  Serial.print("K0LEDG - RW - ");
  Serial.print(RH_K0LEDG, HEX);
  Serial.print(" - ");
  Serial.println(
      (uint16_t) ((((uint16_t) _reg[RH_K0LEDG + 1]) << 8) | _reg[RH_K0LEDG]));
  Serial.print("K0LEDB - RW - ");
  Serial.print(RH_K0LEDB, HEX);
  Serial.print(" - ");
  Serial.println(
      (uint16_t) ((((uint16_t) _reg[RH_K0LEDB + 1]) << 8) | _reg[RH_K0LEDB]));

  Serial.print("K1LEDR - RW - ");
  Serial.print(RH_K1LEDR, HEX);
  Serial.print(" - ");
  Serial.println(((((int16_t) _reg[RH_K1LEDR + 1]) << 8) | _reg[RH_K1LEDR]));
  Serial.print("K1LEDG - RW - ");
  Serial.print(RH_K1LEDG, HEX);
  Serial.print(" - ");
  Serial.println(((((int16_t) _reg[RH_K1LEDG + 1]) << 8) | _reg[RH_K1LEDG]));
  Serial.print("K1LEDB - RW - ");
  Serial.print(RH_K1LEDB, HEX);
  Serial.print(" - ");
  Serial.println(((((int16_t) _reg[RH_K1LEDB + 1]) << 8) | _reg[RH_K1LEDB]));

  Serial.print("K2LEDR - RW - ");
  Serial.print(RH_K2LEDR, HEX);
  Serial.print(" - ");
  Serial.println(((((int16_t) _reg[RH_K2LEDR + 1]) << 8) | _reg[RH_K2LEDR]));
  Serial.print("K2LEDG - RW - ");
  Serial.print(RH_K2LEDG, HEX);
  Serial.print(" - ");
  Serial.println(((((int16_t) _reg[RH_K2LEDG + 1]) << 8) | _reg[RH_K2LEDG]));
  Serial.print("K2LEDB - RW - ");
  Serial.print(RH_K2LEDB, HEX);
  Serial.print(" - ");
  Serial.println(((((int16_t) _reg[RH_K2LEDB + 1]) << 8) | _reg[RH_K2LEDB]));

  Serial.print("K3LEDR - RW - ");
  Serial.print(RH_K3LEDR, HEX);
  Serial.print(" - ");
  Serial.println(((((int16_t) _reg[RH_K3LEDR + 1]) << 8) | _reg[RH_K3LEDR]));
  Serial.print("K3LEDG - RW - ");
  Serial.print(RH_K3LEDG, HEX);
  Serial.print(" - ");
  Serial.println(((((int16_t) _reg[RH_K3LEDG + 1]) << 8) | _reg[RH_K3LEDG]));
  Serial.print("K3LEDB - RW - ");
  Serial.print(RH_K3LEDB, HEX);
  Serial.print(" - ");
  Serial.println(((((int16_t) _reg[RH_K3LEDB + 1]) << 8) | _reg[RH_K3LEDB]));

  Serial.print("FLAGS - RW - ");
  Serial.print(RH_FLAGS, HEX);
  Serial.print(" - ");
  pr_byte(_reg[RH_FLAGS]);
  Serial.println();

  Serial.print("STATE - R0 - ");
  Serial.print(RH_STATE, HEX);
  Serial.print(" - ");
  pr_byte(_reg[RH_STATE]);
  Serial.println();

  Serial.print("K0CNT - R0 - ");
  Serial.print(RH_K0CNT, HEX);
  Serial.print(" - ");
  Serial.println((int8_t)_reg[RH_K0CNT]);

  Serial.print("K1CNT - R0 - ");
  Serial.print(RH_K1CNT, HEX);
  Serial.print(" - ");
  Serial.println((int8_t)_reg[RH_K1CNT]);

  Serial.print("K2CNT - R0 - ");
  Serial.print(RH_K2CNT, HEX);
  Serial.print(" - ");
  Serial.println((int8_t)_reg[RH_K2CNT]);

  Serial.print("K3CNT - R0 - ");
  Serial.print(RH_K3CNT, HEX);
  Serial.print(" - ");
  Serial.println((int8_t)_reg[RH_K3CNT]);

  Serial.print("ACCLX - R0 - ");
  Serial.print(RH_ACCLX, HEX);
  Serial.print(" - ");
  Serial.println(
      (int16_t) ((((int16_t) _reg[RH_ACCLX + 1]) << 8) | _reg[RH_ACCLX]));
  Serial.print("ACCLY - R0 - ");
  Serial.print(RH_ACCLY, HEX);
  Serial.print(" - ");
  Serial.println(
      (int16_t) ((((int16_t) _reg[RH_ACCLY + 1]) << 8) | _reg[RH_ACCLY]));
  Serial.print("ACCLZ - R0 - ");
  Serial.print(RH_ACCLZ, HEX);
  Serial.print(" - ");
  Serial.println(
      (int16_t) ((((int16_t) _reg[RH_ACCLZ + 1]) << 8) | _reg[RH_ACCLZ]));

  Serial.print("RFRSH - R0 - ");
  Serial.print(RH_RFRSH, HEX);
  Serial.print(" - ");
  Serial.print(((((int16_t) _reg[RH_RFRSH + 1]) << 8) | _reg[RH_RFRSH]));
  Serial.println("Hz");
  Serial.println("###################");

}

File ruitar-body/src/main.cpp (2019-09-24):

#include <Arduino.h>
#include <Bounce2.h>
#include <TeensyView.h>
#include "RuiBody.h"
#include "RuiHead.h"
#include "RuiMIDI.h"
#include "RuiPreset.h"

#define MIDI_DEBUG 0
#define SENSOR_DEBUG 0

// Ethernet SPI -  OR  - ESP32 + SLIPSerial 
#define PIN_ETH_MOSI 0 // ESP RX1
#define PIN_ETH_MISO 1 // ESP TX1
#define PIN_ETH_RST 2
#define PIN_ETH_SCK 32
#define PIN_ETH_CS 31

// Head I2C Pins
#define PIN_HEAD_SCL 3
#define PIN_HEAD_SDA 4

// Button LED output pins
#define PIN_LED0 5
#define PIN_LED1 6 // XXX TAB SPI CS (Memory)
#define PIN_LED2 7 // XXX TAB SPI MOSI0
#define PIN_LED3 8

// Display SPI pins
#define PIN_DISPLAY_CS 10
#define PIN_DISPLAY_MOSI 11 // TAB I2S MCLK
#define PIN_DISPLAY_SCK 13 // TAB I2S RX
#define PIN_DISPLAY_RST 24 
#define PIN_DISPLAY_DC 25

// Soft-pot "string" analog input pins
#define PIN_S0 14 // XXX TAB SPI SCK0
#define PIN_S1 15
#define PIN_S2 16
#define PIN_S3 17

// FSR "pad" analog input pins
#define PIN_P0 18 // TAB I2C SDA0
#define PIN_P1 19 // TAB I2C SCL0
#define PIN_P2 20
#define PIN_P3 21 

// Joystick input pins
#define PIN_JSX 22 // TAB I2S TX
#define PIN_JSY 23 // TAB I2S LRCLK

// Fader potentiometer input pins
#define PIN_F0 33
#define PIN_F1 34
#define PIN_F2 35
#define PIN_F3 36

// Momentary button input pins (treated as toggles)
#define PIN_T0 26
#define PIN_T1 27
#define PIN_T2 28
#define PIN_T3 29

#define PIN_HEAD_RESET 9  // TAB I2S BCLK

#define PIN_UNUSED_12 12  // XXX TAB SPI MISO0
#define PIN_UNUSED_30 30  
#define PIN_UNUSED_38 38
#define PIN_UNUSED_39 39

uint32_t _elapsed;
uint16_t _rate;
uint8_t _debug;

SensorCalibration sensorCalibration;

// The display instance
// TeensyView display(PIN_DISPLAY_RST, PIN_DISPLAY_DC, PIN_DISPLAY_CS,
// PIN_DISPLAY_SCK, PIN_DISPLAY_MOSI, 64, &SPI);
TeensyView display(PIN_DISPLAY_RST, PIN_DISPLAY_DC, PIN_DISPLAY_CS,
                   PIN_DISPLAY_SCK, PIN_DISPLAY_MOSI);

// The toggle buttons (body)
Bounce toggle0 = Bounce();
Bounce toggle1 = Bounce();
Bounce toggle2 = Bounce();
Bounce toggle3 = Bounce();

// Pointer array for convienience
Bounce *toggles[] = {&toggle0, &toggle1, &toggle2, &toggle3};

uint8_t stringPins[] = {PIN_S0, PIN_S1, PIN_S2, PIN_S3};
uint8_t padPins[] = {PIN_P0, PIN_P1, PIN_P2, PIN_P3};
uint8_t faderPins[] = {PIN_F0, PIN_F1, PIN_F2, PIN_F3};
uint8_t buttonPins[] = {PIN_T0, PIN_T1, PIN_T2, PIN_T3};
uint8_t ledPins[] = {PIN_LED0, PIN_LED1, PIN_LED2, PIN_LED3};

/******** GLOBAL STATE VARIABLES *******/

// Timing and iteration
int16_t iter = 0;
uint64_t time = micros();
uint64_t iterDuration = 0;
uint64_t displayDuration = 0;
uint64_t modXDuration[10];

// The current preset
int8_t currentPreset = 0;

// Timing mode shows performance information on the display
bool timingMode = false;

// Config mode enables preset configuration changes
bool configMode = false;

/******** SETUP *******/

bool on = true;

void setup() {

  Serial.begin(1000000);
  delay(100);
  // Serial.println("Welcome to the ruitar body!");

  _debug = 1;
  _elapsed = 0;
  _rate = 0;

  pinMode(PIN_JSX, INPUT);
  pinMode(PIN_JSY, INPUT);

  // Setup body buttons
  for (size_t s = 0; s < NN; s++) {
    pinMode(buttonPins[s], INPUT);
    toggles[s]->attach(buttonPins[s]);
    toggles[s]->interval(2);
    pinMode(ledPins[s], OUTPUT);
    pinMode(stringPins[s], INPUT);
    pinMode(padPins[s], INPUT);
    pinMode(faderPins[s], INPUT);
  }

  // Serial.print("Setting up the display...");
  display.begin();
  display.setFontType(0);
  delay(100);
  // Serial.println("OK");

  // Serial.print("Setting up the presets...");
  RuiPreset.begin("/ruitar/presets/");
  delay(100);
  // Serial.println("OK");

  // pinMode(PIN_HEAD_RESET, OUTPUT);
  // digitalWrite(PIN_HEAD_RESET, HIGH);
  // RuiHead.begin();
  // delay(100);

  RuiMIDI.begin();

  // Serial.print("Setting up the synth...");
  //RuiSynth.begin();
  // Serial.println("OK");

}

/******** LOOP *******/

void loop() {
  uint32_t iter_start = micros();

  // Update the head first...
// if (iter % 500 == 0) {
//   RuiHead.update();
// }
  
  if (RuiBody.sensorMode == PHY) {
    // Iterate over the iterables...
    for (size_t s = 0; s < NN; s++) {
      // Read the strings...
      RuiBody.sensorsLast.stringsV[s] = RuiBody.sensors.stringsV[s];
      RuiBody.sensors.stringsV[s] = analogRead(stringPins[s]);
      // ..and the pads...
      RuiBody.sensorsLast.padsV[s] = RuiBody.sensors.padsV[s];
      RuiBody.sensors.padsV[s] = analogRead(padPins[s]);
      // ..and the faders...
      RuiBody.sensorsLast.fadersV[s] = RuiBody.sensors.fadersV[s];
      RuiBody.sensors.fadersV[s] = analogRead(faderPins[s]);
      // ..and the body toggle buttons...
      toggles[s]->update();
      RuiBody.sensorsLast.togglesV[s] = RuiBody.sensors.togglesV[s];
      RuiBody.sensors.togglesV[s] = toggles[s]->read();
      // // ..and the head buttons...
      // RuiBody.sensorsLast.buttonsV[s] = RuiBody.sensors.buttonsV[s];
      // RuiBody.sensors.buttonsV[s] = RuiHead.button(s);
      // // ..and the head knobs.
      // RuiBody.sensorsLast.knobsV[s] = RuiBody.sensors.knobsV[s];
      // RuiBody.sensors.knobsV[s] = RuiHead.knob(s);
    }
    // // Now the non-iterables
    // // First read the X and Y joystick axis
    // RuiBody.sensorsLast.jsXv = RuiBody.sensors.jsXv;
    // RuiBody.sensors.jsXv = analogRead(PIN_JSX);
    // RuiBody.sensorsLast.jsYv = RuiBody.sensors.jsYv;
    // RuiBody.sensors.jsYv = analogRead(PIN_JSY);

    // // ...now the head accellerometer values
    // RuiBody.sensorsLast.accXv = RuiBody.sensors.accXv;
    // RuiBody.sensors.accXv = RuiHead.accelX();
    // RuiBody.sensorsLast.accYv = RuiBody.sensors.accYv;
    // RuiBody.sensors.accYv = RuiHead.accelY();
    // RuiBody.sensorsLast.accZv = RuiBody.sensors.accZv;
    // RuiBody.sensors.accZv = RuiHead.accelZ();
  }

  // if (configMode) {
  //   // We're in config mode. Re-route the head knob and button values to the
  //   // preset class
  //   RuiPreset.update();
  // }

  RuiMIDI.update();
  RuiMIDI.dispatch();

  //RuiOSC.update();
  //RuiOSC.dispatch();

  // RuiSynth.update();
  // RuiSynth.dispatch();


  // Dispatch any feedback now
  for (size_t s = 0; s < NN; s++) {
    if (RuiBody.feedback.toggleLeds[s] != RuiBody.feedbackLast.toggleLeds[s]) {
      digitalWrite(ledPins[s], RuiBody.feedback.toggleLeds[s]);
    }
    if (RuiBody.feedback.headLedsR[s] != RuiBody.feedbackLast.headLedsR[s]) {
      RuiHead.red(s, RuiBody.feedback.headLedsR[s]);
    }
    if (RuiBody.feedback.headLedsG[s] != RuiBody.feedbackLast.headLedsG[s]) {
      RuiHead.green(s, RuiBody.feedback.headLedsG[s]);
    }
    if (RuiBody.feedback.headLedsB[s] != RuiBody.feedbackLast.headLedsB[s]) {
      RuiHead.blue(s, RuiBody.feedback.headLedsB[s]);
    }
  }
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

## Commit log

2018-08-31 Restructure. Rename. Document.
    [ADIO-0-15.sch, ruitar-body.kicad_pcb, ruitar-body.sch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]
2018-10-31 Add the base for a headstock protective case
    [kxmx_ruitar_head_case.scad]
2019-09-16 Simplify a few things to make debugging a wiring problem easier...
    [main.cpp]
